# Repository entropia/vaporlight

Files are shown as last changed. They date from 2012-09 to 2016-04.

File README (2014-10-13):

Vaporlight
==========

The Vaporlight is Entropias LED lighting system.

More documentation (including pictures) is available
at https://entropia.de/Vaporlight.

Where to find what
------------------

/HACKING                       Describes some internals
/hardware                      Schematics and PCB layouts (Eagle)
/vaporware/led-boards          Firmware for the LED modules (C)
/config                        OpenOCD config files
/vaporware/emulator            Hardware emulator (Python)
/vaporware/daemon              TCP <-> Bus router (Scala)
/vaporware/language_bindings   Libraries for talking to the router (Python, C++)
/misc                          z.B. Schutzecken zum 3D-Drucken (OpenSCAD)

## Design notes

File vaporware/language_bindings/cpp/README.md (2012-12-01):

#Overview
This Reposetory provides a C++-Library that enables easy usage of the 
Vaporlight and a simple cli-tool to controll the LEDs directly.

## The library
The library provides an interface that is very easy to use and completly hides every networking or lowlevel-stuff from
it's users. It is implemented in a way that makes the usage of the header very cheap in compiletime though.

## The shell
The shell is a primitive userinterface for the vaporlight. Nevertheless it should be enough to do basic testing of the
vaporlight or figuring out, how the library can be used.

## License
vaporpp is free Software and licensed under the GNU Affero General Public License. (see license.txt)

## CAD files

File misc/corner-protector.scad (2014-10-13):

edge_length = 25;
edge_stop_length = edge_length - 10;
wall_width = 2;
wall_height = 2;
slot_height = 3;

total_height = 2 * wall_height + slot_height;

round_radius = 3;


// Rotate everything so that the long side points down
rotate([90,135,0])

// Construct body
difference() {
    // Outer extruded triangle
    linear_extrude(height = total_height, center = true, convexity = 10, $fn=100) {
        polygon(points=[[0,0],[edge_length,0],[0,edge_length]], paths=[[0,1,2]]);
    }

    // Inner extruded triangle
    linear_extrude(height = slot_height, center = true, convexity = 10, $fn=100) {
        polygon(points=[[wall_width,wall_width],[edge_length,wall_width],[wall_width,edge_length]], paths=[[0,1,2]]);
    }

    // Round off 90deg corner
    difference(){
        cube([2*round_radius,2*round_radius,total_height], center = true);

        translate([round_radius, round_radius, 0])
            cylinder (h = total_height, r=round_radius, center = true, $fn=100);
    }

    // Cut off 45deg corners
    translate([edge_length, 0, 0])
        rotate([0,0,45])
            cube([edge_length - edge_stop_length, edge_length - edge_stop_length, edge_length - edge_stop_length], center=true);
    translate([0, edge_length, 0])
        rotate([0,0,45])
            cube([edge_length - edge_stop_length, edge_length - edge_stop_length, edge_length - edge_stop_length], center=true);
}

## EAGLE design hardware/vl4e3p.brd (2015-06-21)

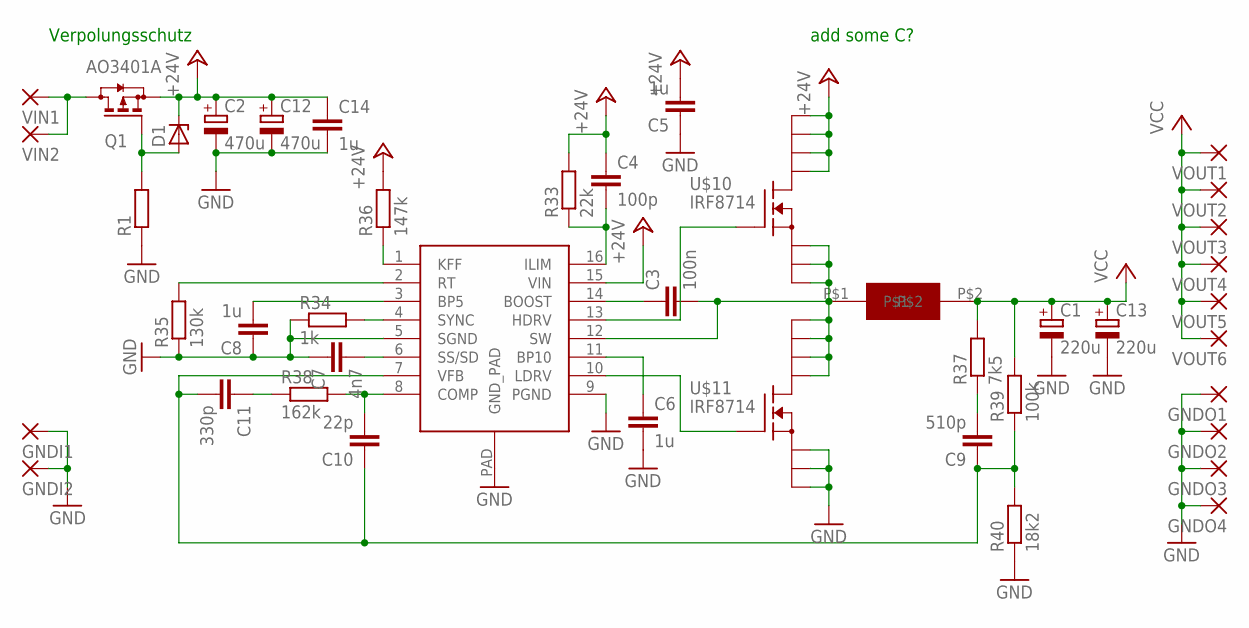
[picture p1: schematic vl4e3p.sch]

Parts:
C1, C13: 220u; E3,5-8
C2, C12: 470u; E3,5-8
C3: 100n; C0805S
C4: 100p; C0805
C5, C6, C8, C14: 1u; C0805
C7: 4n7; C0805
C9: 510p; C0805
C10: 22p; C0805
C11: 330p; C0805
D1: ZENER-DIODESOT23; SOT23
GNDI1, GNDI2: PAD5-2,5; 5-2,5
GNDO1, GNDO2, GNDO3, GNDO4: PAD5-2,5; 5-2,5
Q1: AO3401A; SOT23
R1: R-EU_R0805; R0805
R33: 22k; R0805
R34: 1k; R0805
R35: 130k; R0805
R36: 147k; R0805
R37: 7k5; R0805
R38: 162k; R0805
R39: 100k; R0805
R40: 18k2; R0805
U$1: 6u8; FOO
U$9: TPS40055; TSSOP16
U$10, U$11: IRF8714; SO8
VIN1, VIN2: PAD5-2,5; 5-2,5
VOUT1, VOUT2, VOUT3, VOUT4, VOUT5, VOUT6: PAD5-2,5; 5-2,5

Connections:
+24V: C2.+, C4.1, C5.2, C12.+, C14.1, D1.3 (C), Q1.2 (S), R33.2, R36.2, U$9.15 (VIN), U$10.5 (D), U$10.6 (D), U$10.7 (D), U$10.8 (D)
BOOST: C3.1, U$9.14 (BOOST)
BP10: C6.1, U$9.11 (BP10)
C3: C8.2, U$9.3 (BP5)
COMP: C10.2, R38.2, U$9.8 (COMP)
GND: C1.-, C2.-, C5.1, C6.2, C7.1, C8.1, C12.-, C13.-, C14.2, GNDI1.1, GNDI2.1, GNDO1.1, GNDO2.1, GNDO3.1, GNDO4.1, R1.1, R34.1, R35.1, R40.1, U$9.5 (SGND), U$9.9 (PGND), U$9.PAD (GND_PAD), U$11.1 (S), U$11.2 (S), U$11.3 (S)
HDRV: U$9.13 (HDRV), U$10.4 (G)
ILIM: C4.2, R33.1, U$9.16 (ILIM)
KFF: R36.1, U$9.1 (KFF)
LDRV: U$9.10 (LDRV), U$11.4 (G)
unnamed: C11.1, R38.1
unnamed: C9.2, R37.1
unnamed: D1.1 (A), Q1.1 (G), R1.2
RT: R35.2, U$9.2 (RT)
SS/SD: C7.2, U$9.6 (SS/SD)
SW: C3.2, U$1.P$1, U$9.12 (SW), U$10.1 (S), U$10.2 (S), U$10.3 (S), U$11.5 (D), U$11.6 (D), U$11.7 (D), U$11.8 (D)
SYNC: R34.2, U$9.4 (SYNC)
VCC: C1.+, C13.+, R37.2, R39.2, U$1.P$2, VOUT1.1, VOUT2.1, VOUT3.1, VOUT4.1, VOUT5.1, VOUT6.1
VFB: C9.1, C10.1, C11.2, R39.1, R40.2, U$9.7 (VFB)
VIN: Q1.3 (D), VIN1.1, VIN2.1

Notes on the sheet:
Verpolungsschutz
add some C?

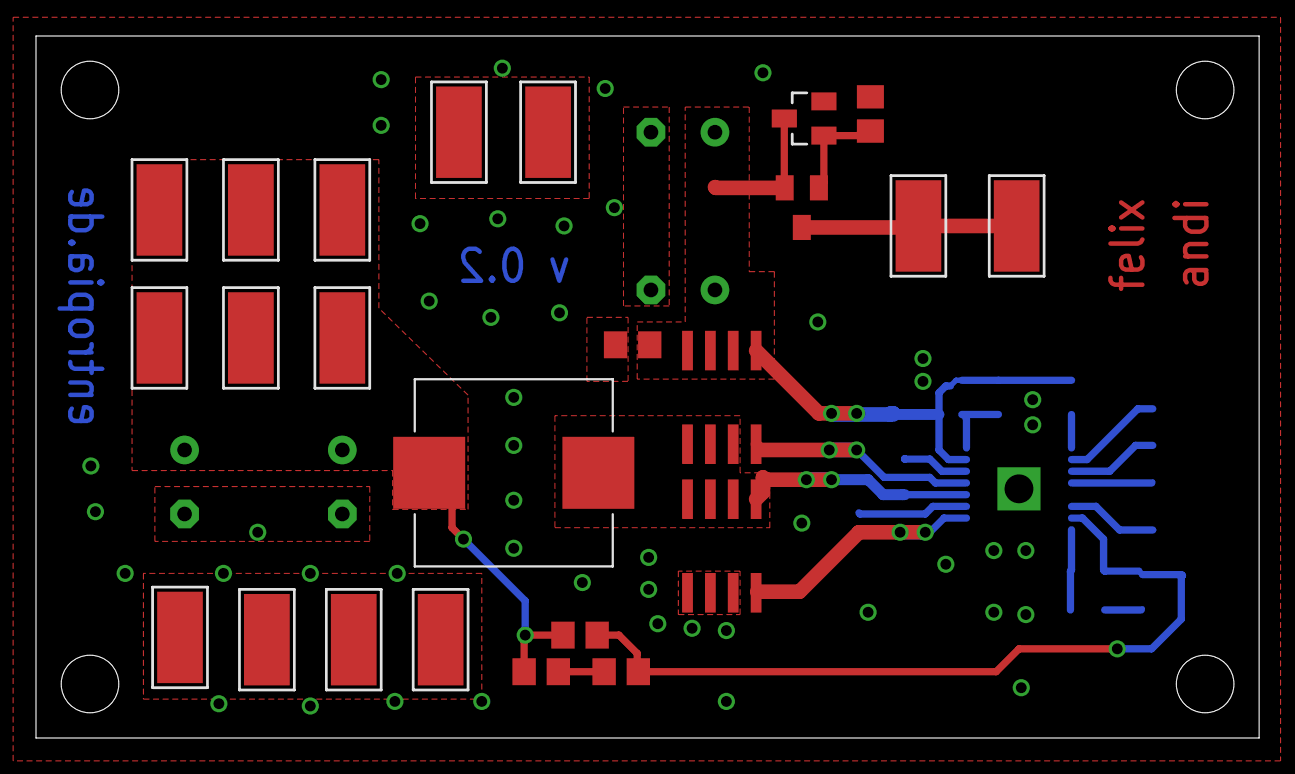
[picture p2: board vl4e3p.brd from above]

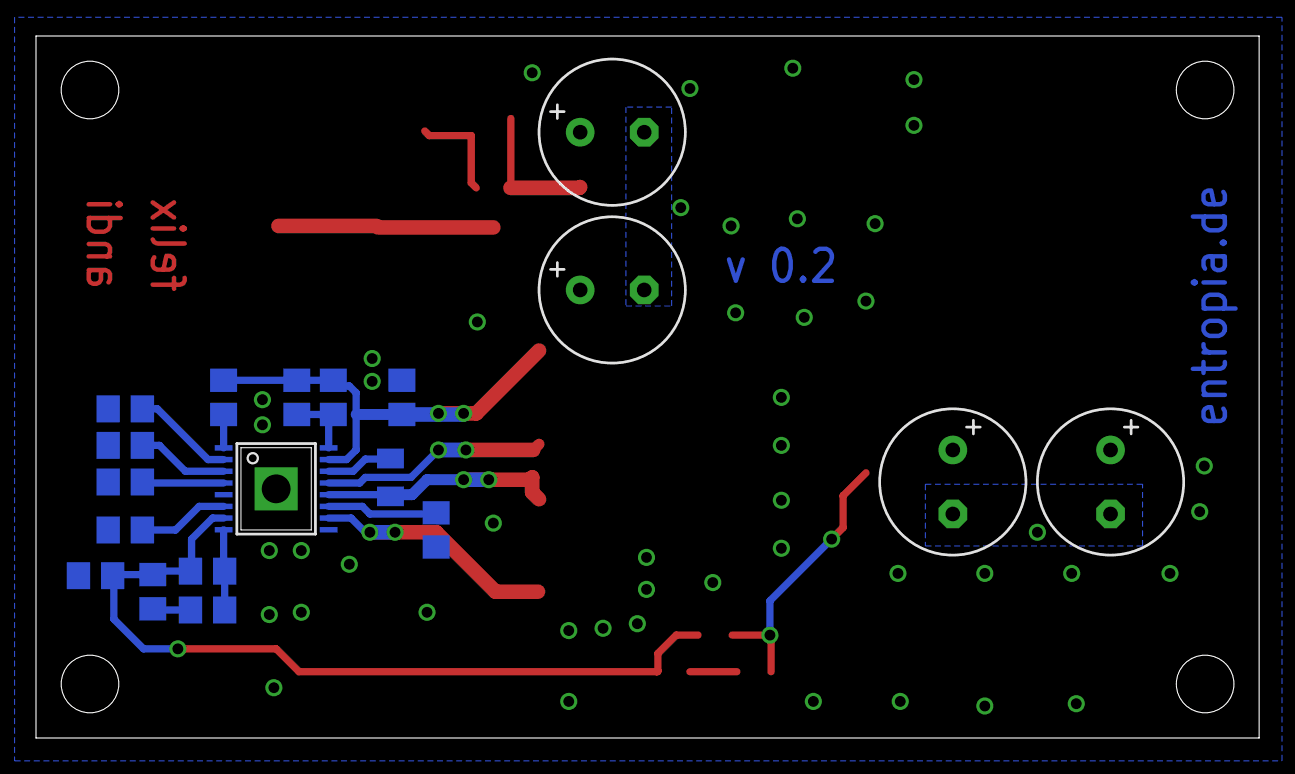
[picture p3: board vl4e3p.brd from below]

Board: 2 copper layers, 68.0 x 39.0 mm, 43 parts (19 on the bottom side), 20 nets.

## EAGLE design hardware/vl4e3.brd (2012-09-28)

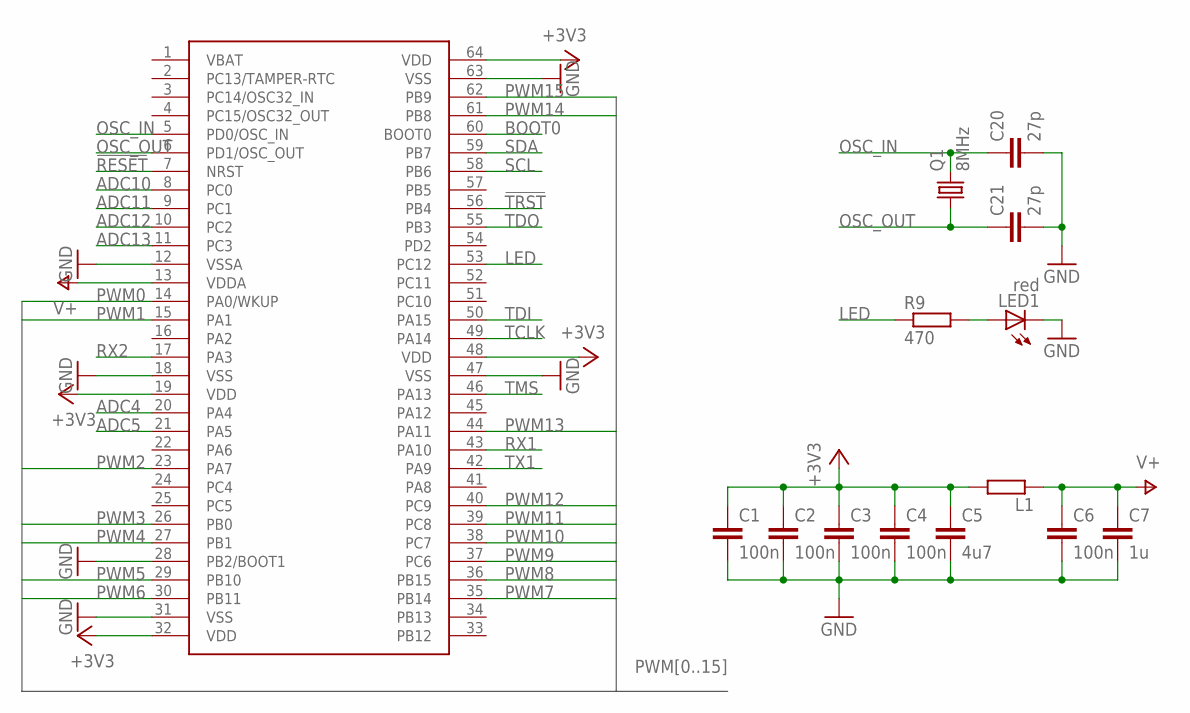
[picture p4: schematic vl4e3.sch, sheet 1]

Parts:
C1, C2, C3, C4, C6: 100n; C0603
C5: 4u7; C0805
C7: 1u; C0805
C20, C21: 27p; C0603
L1: R-EU_R0805; R0805
LED1: red; CHIPLED_0805
Q1: 8MHz; HC49/S
R9: 470; R0805
U$1: STM32F100R; TQFP64-10X10

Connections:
!RESET: U$1.7 (NRST); also elsewhere on the board
!TRST: U$1.56 (PB4); also elsewhere on the board
+3V3: C1.1, C2.1, C3.1, C4.1, C5.1, L1.2, U$1.19 (VDD), U$1.32 (VDD), U$1.48 (VDD), U$1.64 (VDD); also elsewhere on the board
ADC4: U$1.20 (PA4); also elsewhere on the board
ADC5: U$1.21 (PA5); also elsewhere on the board
ADC10: U$1.8 (PC0); also elsewhere on the board
ADC11: U$1.9 (PC1); also elsewhere on the board
ADC12: U$1.10 (PC2); also elsewhere on the board
ADC13: U$1.11 (PC3); also elsewhere on the board
BOOT0: U$1.60 (BOOT0); also elsewhere on the board
GND: C1.2, C2.2, C3.2, C4.2, C5.2, C6.2, C7.2, C20.2, C21.2, LED1.C, U$1.12 (VSSA), U$1.18 (VSS), U$1.28 (PB2/BOOT1), U$1.31 (VSS), U$1.47 (VSS), U$1.63 (VSS); also elsewhere on the board
LED: R9.1, U$1.53 (PC12)
LED_R: LED1.A, R9.2
OSC_IN: C20.1, Q1.2, U$1.5 (PD0/OSC_IN)
OSC_OUT: C21.1, Q1.1, U$1.6 (PD1/OSC_OUT)
PWM0: U$1.14 (PA0/WKUP); also elsewhere on the board
PWM1: U$1.15 (PA1); also elsewhere on the board
PWM2: U$1.23 (PA7); also elsewhere on the board
PWM3: U$1.26 (PB0); also elsewhere on the board
PWM4: U$1.27 (PB1); also elsewhere on the board
PWM5: U$1.29 (PB10); also elsewhere on the board
PWM6: U$1.30 (PB11); also elsewhere on the board
PWM7: U$1.35 (PB14); also elsewhere on the board
PWM8: U$1.36 (PB15); also elsewhere on the board
PWM9: U$1.37 (PC6); also elsewhere on the board
PWM10: U$1.38 (PC7); also elsewhere on the board
PWM11: U$1.39 (PC8); also elsewhere on the board
PWM12: U$1.40 (PC9); also elsewhere on the board
PWM13: U$1.44 (PA11); also elsewhere on the board
PWM14: U$1.61 (PB8); also elsewhere on the board
PWM15: U$1.62 (PB9); also elsewhere on the board
RX1: U$1.43 (PA10); also elsewhere on the board
RX2: U$1.17 (PA3); also elsewhere on the board
SCL: U$1.58 (PB6)
SDA: U$1.59 (PB7)
TCLK: U$1.49 (PA14); also elsewhere on the board
TDI: U$1.50 (PA15); also elsewhere on the board
TDO: U$1.55 (PB3); also elsewhere on the board
TMS: U$1.46 (PA13); also elsewhere on the board
TX1: U$1.42 (PA9); also elsewhere on the board
V+: C6.1, C7.1, L1.1, U$1.13 (VDDA)

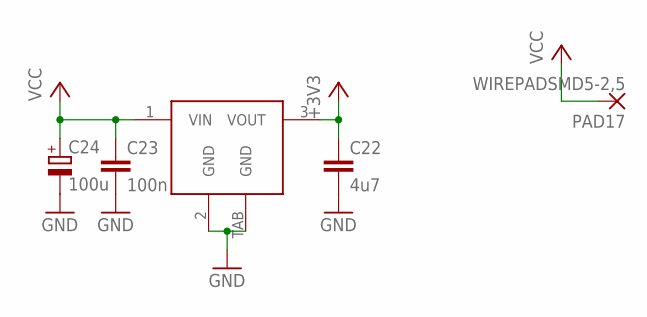
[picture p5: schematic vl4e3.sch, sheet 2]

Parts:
C22: 4u7; C0805
C23: 100n; C0603
C24: 100u; E2,5-6
PAD17: WIREPADSMD5-2,5; 5-2,5
U$10: MIC5209; SOT223

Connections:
+3V3: C22.1, U$10.3 (VOUT); also elsewhere on the board
GND: C22.2, C23.2, C24.-, U$10.2 (GND), U$10.TAB (GND); also elsewhere on the board
VCC: C23.1, C24.+, PAD17.1, U$10.1 (VIN); also elsewhere on the board

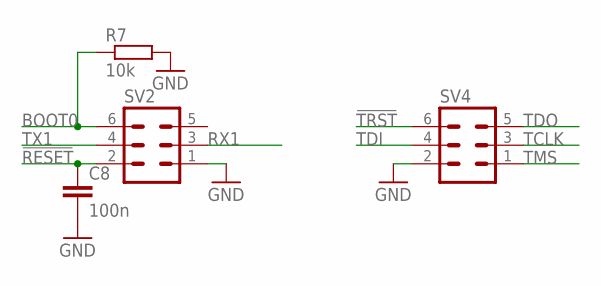
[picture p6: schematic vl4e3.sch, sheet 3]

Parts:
C8: 100n; C0603
R7: 10k; R0603
SV2, SV4: MA03-2

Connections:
!RESET: C8.1, SV2.2; also elsewhere on the board
!TRST: SV4.6; also elsewhere on the board
BOOT0: R7.1, SV2.6; also elsewhere on the board
GND: C8.2, R7.2, SV2.1, SV4.2; also elsewhere on the board
RX1: SV2.3; also elsewhere on the board
TCLK: SV4.3; also elsewhere on the board
TDI: SV4.4; also elsewhere on the board
TDO: SV4.5; also elsewhere on the board
TMS: SV4.1; also elsewhere on the board
TX1: SV2.4; also elsewhere on the board

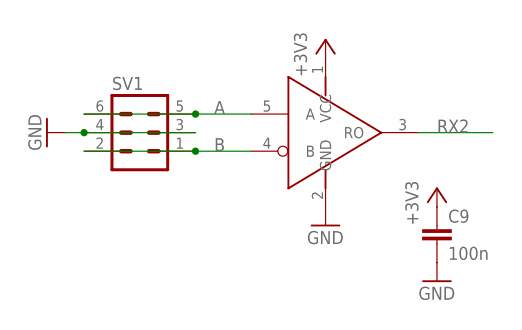
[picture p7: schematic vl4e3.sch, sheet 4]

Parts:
C9: 100n; C0603
SV1: MA03-2
U$13: ISL3280E; SOT23-5L

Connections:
+3V3: C9.1, U$13.1 (VCC); also elsewhere on the board
A: SV1.5, SV1.6, U$13.5 (A)
B: SV1.1, SV1.2, U$13.4 (B)
GND: C9.2, SV1.3, SV1.4, U$13.2 (GND); also elsewhere on the board
RX2: U$13.3 (RO); also elsewhere on the board

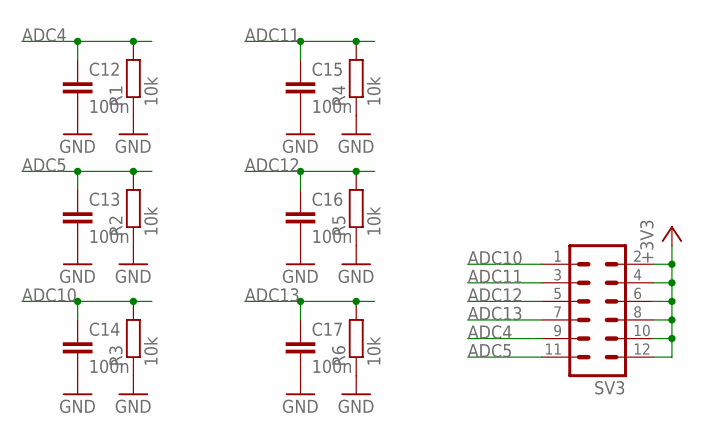
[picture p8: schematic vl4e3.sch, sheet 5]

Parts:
C12, C13, C14, C15, C16, C17: 100n; C0603
R1, R2, R3, R4, R5, R6: 10k; R0603
SV3: MA06-2

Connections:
+3V3: SV3.2, SV3.4, SV3.6, SV3.8, SV3.10, SV3.12; also elsewhere on the board
ADC4: C12.1, R1.2, SV3.9; also elsewhere on the board
ADC5: C13.1, R2.2, SV3.11; also elsewhere on the board
ADC10: C14.1, R3.2, SV3.1; also elsewhere on the board
ADC11: C15.1, R4.2, SV3.3; also elsewhere on the board
ADC12: C16.1, R5.2, SV3.5; also elsewhere on the board
ADC13: C17.1, R6.2, SV3.7; also elsewhere on the board
GND: C12.2, C13.2, C14.2, C15.2, C16.2, C17.2, R1.1, R2.1, R3.1, R4.1, R5.1, R6.1; also elsewhere on the board

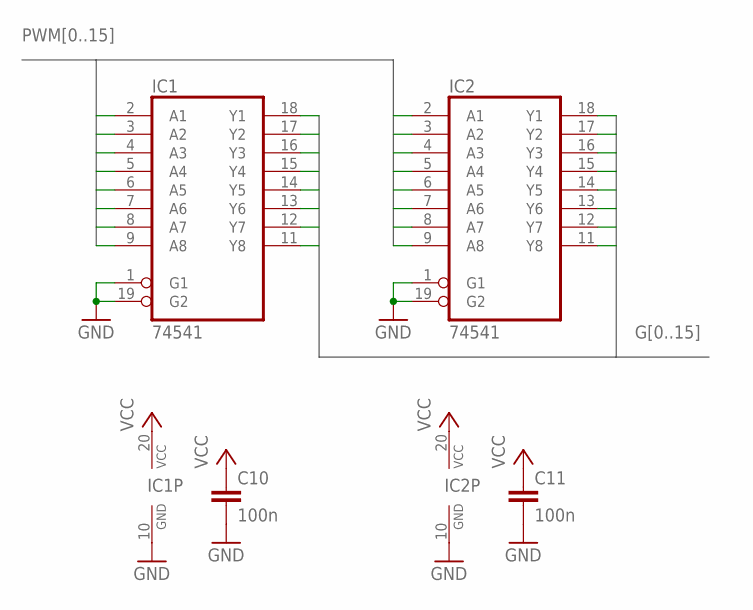
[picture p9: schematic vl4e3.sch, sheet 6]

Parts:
C10, C11: 100n; C0603
IC1, IC2: 74541; TSSOP20

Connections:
G0: IC1.18 (Y1); also elsewhere on the board
G1: IC1.17 (Y2); also elsewhere on the board
G2: IC1.16 (Y3); also elsewhere on the board
G3: IC1.15 (Y4); also elsewhere on the board
G4: IC1.14 (Y5); also elsewhere on the board
G5: IC1.13 (Y6); also elsewhere on the board
G6: IC1.12 (Y7); also elsewhere on the board
G7: IC1.11 (Y8); also elsewhere on the board
G8: IC2.18 (Y1); also elsewhere on the board
G9: IC2.17 (Y2); also elsewhere on the board
G10: IC2.16 (Y3); also elsewhere on the board
G11: IC2.15 (Y4); also elsewhere on the board
G12: IC2.14 (Y5); also elsewhere on the board
G13: IC2.13 (Y6); also elsewhere on the board
G14: IC2.12 (Y7); also elsewhere on the board
G15: IC2.11 (Y8); also elsewhere on the board
GND: C10.2, C11.2, IC1.1 (G1), IC1.10 (GND), IC1.19 (G2), IC2.1 (G1), IC2.10 (GND), IC2.19 (G2); also elsewhere on the board
PWM0: IC1.2 (A1); also elsewhere on the board
PWM1: IC1.3 (A2); also elsewhere on the board
PWM2: IC1.4 (A3); also elsewhere on the board
PWM3: IC1.5 (A4); also elsewhere on the board
PWM4: IC1.6 (A5); also elsewhere on the board
PWM5: IC1.7 (A6); also elsewhere on the board
PWM6: IC1.8 (A7); also elsewhere on the board
PWM7: IC1.9 (A8); also elsewhere on the board
PWM8: IC2.2 (A1); also elsewhere on the board
PWM9: IC2.3 (A2); also elsewhere on the board
PWM10: IC2.4 (A3); also elsewhere on the board
PWM11: IC2.5 (A4); also elsewhere on the board
PWM12: IC2.6 (A5); also elsewhere on the board
PWM13: IC2.7 (A6); also elsewhere on the board
PWM14: IC2.8 (A7); also elsewhere on the board
PWM15: IC2.9 (A8); also elsewhere on the board
VCC: C10.1, C11.1, IC1.20 (VCC), IC2.20 (VCC); also elsewhere on the board

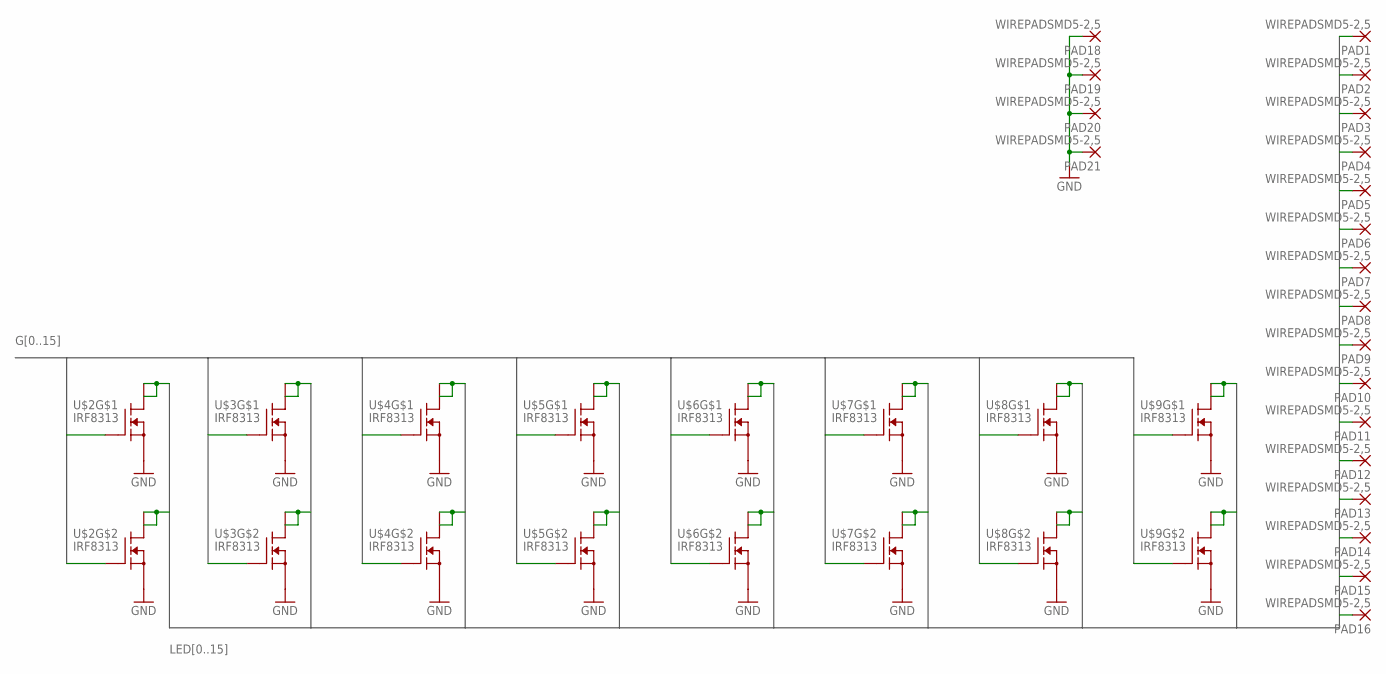
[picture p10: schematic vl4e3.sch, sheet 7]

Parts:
PAD1, PAD2, PAD3, PAD4, PAD5, PAD6, PAD7, PAD8, PAD9, PAD10, PAD11, PAD12, PAD13, PAD14, PAD15, PAD16, PAD18, PAD19, PAD20, PAD21: WIREPADSMD5-2,5; 5-2,5
U$2, U$3, U$4, U$5, U$6, U$7, U$8, U$9: IRF8313; SO-08

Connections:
G0: U$2.2 (G); also elsewhere on the board
G1: U$2.4 (G); also elsewhere on the board
G2: U$3.2 (G); also elsewhere on the board
G3: U$3.4 (G); also elsewhere on the board
G4: U$4.2 (G); also elsewhere on the board
G5: U$4.4 (G); also elsewhere on the board
G6: U$5.2 (G); also elsewhere on the board
G7: U$5.4 (G); also elsewhere on the board
G8: U$6.2 (G); also elsewhere on the board
G9: U$6.4 (G); also elsewhere on the board
G10: U$7.2 (G); also elsewhere on the board
G11: U$7.4 (G); also elsewhere on the board
G12: U$8.2 (G); also elsewhere on the board
G13: U$8.4 (G); also elsewhere on the board
G14: U$9.2 (G); also elsewhere on the board
G15: U$9.4 (G); also elsewhere on the board
GND: PAD18.1, PAD19.1, PAD20.1, PAD21.1, U$2.1 (S), U$2.3 (S), U$3.1 (S), U$3.3 (S), U$4.1 (S), U$4.3 (S), U$5.1 (S), U$5.3 (S), U$6.1 (S), U$6.3 (S), U$7.1 (S), U$7.3 (S), U$8.1 (S), U$8.3 (S), U$9.1 (S), U$9.3 (S); also elsewhere on the board
LED0: PAD1.1, U$2.7 (D), U$2.8 (D)
LED1: PAD2.1, U$2.5 (D), U$2.6 (D)
LED2: PAD3.1, U$3.7 (D), U$3.8 (D)
LED3: PAD4.1, U$3.5 (D), U$3.6 (D)
LED4: PAD5.1, U$4.7 (D), U$4.8 (D)
LED5: PAD6.1, U$4.5 (D), U$4.6 (D)
LED6: PAD7.1, U$5.7 (D), U$5.8 (D)
LED7: PAD8.1, U$5.5 (D), U$5.6 (D)
LED8: PAD9.1, U$6.7 (D), U$6.8 (D)
LED9: PAD10.1, U$6.5 (D), U$6.6 (D)
LED10: PAD11.1, U$7.7 (D), U$7.8 (D)
LED11: PAD12.1, U$7.5 (D), U$7.6 (D)
LED12: PAD13.1, U$8.7 (D), U$8.8 (D)
LED13: PAD14.1, U$8.5 (D), U$8.6 (D)
LED14: PAD15.1, U$9.7 (D), U$9.8 (D)
LED15: PAD16.1, U$9.5 (D), U$9.6 (D)

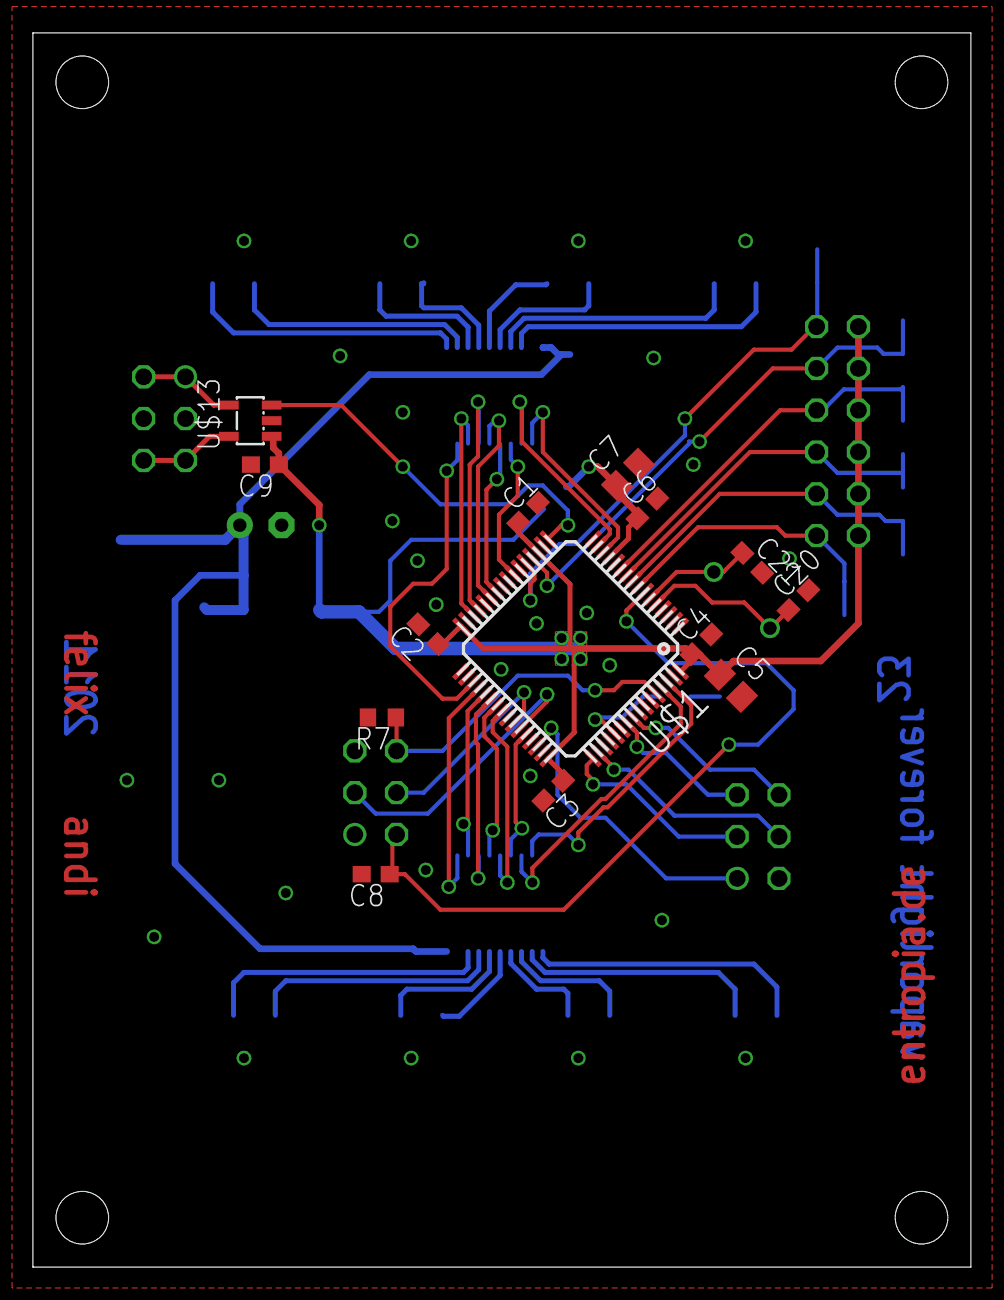
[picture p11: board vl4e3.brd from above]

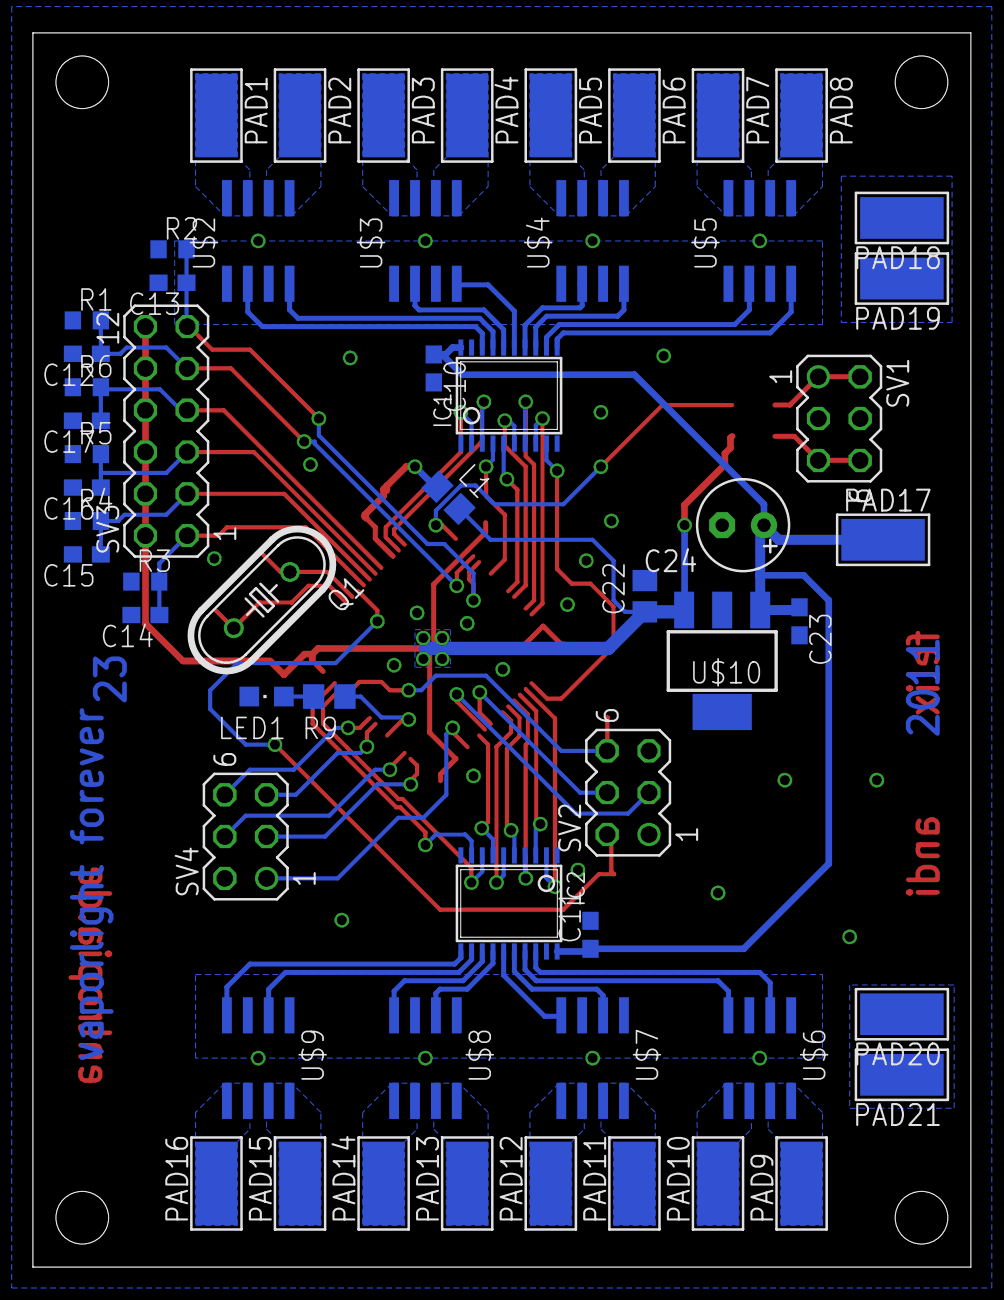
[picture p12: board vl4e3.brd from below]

Board: 2 copper layers, 57.0 x 75.0 mm, 71 parts (57 on the bottom side), 74 nets.

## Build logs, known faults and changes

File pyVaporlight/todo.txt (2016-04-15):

- Lua implementation not testet yet
- write lua effects
- rewrite config style
- Flask frontend
    - control lua scripts
    - control master brightness
    - see all running vaporlight effects (incl. vapornet)

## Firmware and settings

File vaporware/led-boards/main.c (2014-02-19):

/*
  This is the main program file for the Vaporlight Forever LED board controller.
*/
#include "main.h"

#include "color.h"
#include "command.h"
#include "config.h"
#include "console.h"
#include "debug.h"
#include "error.h"
#include "fail.h"
#include "git_version.h"
#include "heat.h"
#include "pwm.h"
#include "usart1.h"
#include "usart2.h"

/*
 * Set to 1 by the systick timer when a heat check
 * should be done.
 */
volatile int do_heat_check;

/*
 * What to do when overheat is detected.
 */
static void panic_on_overheat() {
	pwm_set_state(PWM_STOP);
	error(ER_HEAT, STR_WITH_LEN("Overheat!"), EA_RESET);
}

/*
 * Display the current git revision as colors.
 *
 * If there is no channel mapping yet, display a dim white instead.
 */
static void display_boot_colors(bool have_channel_mapping) {
	uint32_t mask = 1 << 31;

	for(uint8_t c = 0; c < 15; c++) {
		if(have_channel_mapping) {
			uint8_t pwm_channel = convert_channel_index(c);

			pwm_set_brightness(pwm_channel, (GIT_VERSION_HEX & mask) ? 0xFFFF : 0x0);

			mask >>= 1;
		} else {
			pwm_set_brightness(c, 0x7FFF);
		}
	}

	pwm_send_frame();
}

/*
 * Main program. Initializes all the modules and then enters the main loop.
 * The actual work is done in command.c.
 */
int main() {
	unsigned char *command;
	error_t ret;
	vl_mode_t mode;

	usart1_init();

#ifdef TRACE_STARTUP
	dled_off();
#endif

	pwm_init();

	heat_init(panic_on_overheat);

	ret = load_config();

	// Display the version number on lights during bootup
	display_boot_colors(ret == E_SUCCESS);

	mode = console_ask_mode();

	pwm_set_state(PWM_STOP);

	if (ret == E_SUCCESS) {
		// We are running in normal mode with config available.
		// That's OK.
	} else if (ret == E_NOCONFIG && mode != CONFIG_MODE) {
		error(ER_NO_CONFIG, STR_WITH_LEN("No configuration found"), EA_PANIC);
	} else if (ret != E_NOCONFIG && ret != E_SUCCESS) {
		error(ER_BUG, STR_WITH_LEN("Flash read error"), EA_PANIC);
	} else {
		// We are running in config mode with no config available.
		// That's OK.
	}

	// Enable interrupts for heat check.
	__asm("cpsie i");

	pwm_set_state(PWM_ON);

	// If we are running in config mode, first start the config
	// console.  The user may choose to continue running the board
	// after configuration is done, so we must be able to continue
	// as if in normal mode.
	if (mode == CONFIG_MODE) {
		console_run();
	}

	// We are now, regardless of the value of mode, in normal mode.

	command_init();
	usart2_init();

	while (1) {
		command = usart2_next_command();

		if (command != (unsigned char*) 0) {
#ifdef TRACE_COMMANDS
			debug_string("C:");
#endif
			ret = run_command(command);

			if (ret != E_SUCCESS) {
				error(ER_USART_RX, STR_WITH_LEN("Bogus USART command."), EA_RESUME);
#ifdef TRACE_ERRORS
				debug_sint(ret, 0);
				debug_string(" ");
				for (int i = 0; i < 36; i++) {
					debug_hex(command[i], 2);
				}
#endif
			}
		}

		if (do_heat_check) {
#ifdef TRACE_HEAT
			debug_string("H\n");
#endif
			heat_timer_tick();

			do_heat_check = 0;
		}
	}

	error(ER_BUG, STR_WITH_LEN("End of main reached!"), EA_PANIC);

	return 0;
}

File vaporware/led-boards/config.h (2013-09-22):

#ifndef CONFIG_H
#define CONFIG_H

#include <stdint.h>
#include "stm_include/stm32/timer.h"

#include "error.h"
#include "fixedpoint.h"
#include "pwm.h"

/*
 * Configuration to be set at compile time.
 */

// Number of milliseconds to wait between switching of the debug LED.
#define DEBUG_LED_SPEED 125 // 1/8 seconds per dot.

// Length of this module in LEDs
#define MODULE_LENGTH 16

#define RGB_LED_COUNT ((MODULE_LENGTH)/3)

// Mapping from timer channels to PWM registers.
static volatile uint32_t * const TIMER_CHANNELS[MODULE_LENGTH] = {
	&TR(TIM2,  CCR1),
	&TR(TIM2,  CCR2),
	&TR(TIM1,  CCR1),
	&TR(TIM1,  CCR2),
	&TR(TIM1,  CCR3),
	&TR(TIM2,  CCR3),
	&TR(TIM2,  CCR4),
	&TR(TIM15, CCR1),
	&TR(TIM15, CCR2),
	&TR(TIM3,  CCR1),
	&TR(TIM3,  CCR2),
	&TR(TIM3,  CCR3),
	&TR(TIM3,  CCR4),
	&TR(TIM1,  CCR4),
	&TR(TIM16, CCR1),
	&TR(TIM17, CCR1)
};

// Baud rate register for the USARTs.
#if BUS_BAUDRATE == 115200
// Divider 13.0 * 16 = 208.3: 115200 baud at 24MHz
static const int USART_BAUD_VALUE = (13 << 4) | 0;
#else
 #if BUS_BAUDRATE == 500000
// Divider 3.0 * 16 = 48.0: 500000 baud at 24MHz
static const int USART_BAUD_VALUE = (3 << 4) | 0;
 #else
  #error "Only baud rates 115200 and 500000 are supported"
 #endif
#endif
// Divider 13.0 * 16 = 208.3: 115200 baud at 24MHz
static const int CONSOLE_BAUD_VALUE = (13 << 4) | 0;

// Timeout for the user reaction to enter config mode, in ms.
static const int ASK_MODE_TIMEOUT = 3000;

// Number of failures on which to raise an error.
static const int USART_FAIL_TRESHOLD = 20;

// Number of USART command buffers.
#define USART_BUFFER_COUNT 4
// Length of a USART command buffer
#define CMD_BUFFER_LEN 36

// Start-of-command marker
#define START_MARK 0x55
// Byte used for escaping
#define ESCAPE_MARK 0x54

// Temperature sensor count
#define HEAT_SENSOR_LEN 6


// Number base used for reading user input in the config console.
#define CONSOLE_READ_BASE 10


// Temperature sensor ADC ports
static const uint8_t HEAT_ADC_PORTS[HEAT_SENSOR_LEN] = {
	4,
	5,
	10,
	11,
	12,
	13,
};

// How many bits to use for the PWM.
#define PWM_BITS 16

// The value to which the PWM counters will be reset.
#if PWM_BITS == 16
	// Use 0xfffe so that a value of 0xffff is really 100% on
	#define PWM_RELOAD 0xfffe
#else
	#define PWM_RELOAD ((1 << PWM_BITS) - 1)
#endif

// Sample time for the heat sensors.
#define ADC_SAMPLE_TIME 0x7 // 239.5 cycles (50kHz)
static const int ADC_SAMPLE_TIME_1 =
	((ADC_SAMPLE_TIME & 0x7) << 0) |
	((ADC_SAMPLE_TIME & 0x7) << 3) |
	((ADC_SAMPLE_TIME & 0x7) << 6) |
	((ADC_SAMPLE_TIME & 0x7) << 9) |
	((ADC_SAMPLE_TIME & 0x7) << 12) |
	((ADC_SAMPLE_TIME & 0x7) << 15) |
	((ADC_SAMPLE_TIME & 0x7) << 18) |
	((ADC_SAMPLE_TIME & 0x7) << 21);

static const int ADC_SAMPLE_TIME_2 =
	((ADC_SAMPLE_TIME & 0x7) << 0) |
	((ADC_SAMPLE_TIME & 0x7) << 3) |
	((ADC_SAMPLE_TIME & 0x7) << 6) |
	((ADC_SAMPLE_TIME & 0x7) << 9) |
	((ADC_SAMPLE_TIME & 0x7) << 12) |
	((ADC_SAMPLE_TIME & 0x7) << 15) |
	((ADC_SAMPLE_TIME & 0x7) << 18) |
	((ADC_SAMPLE_TIME & 0x7) << 21) |
	((ADC_SAMPLE_TIME & 0x7) << 24) |
	((ADC_SAMPLE_TIME & 0x7) << 27);

// Number of failures on which to raise an error.
static const int HEAT_FAIL_TRESHOLD = 20;

// Initial contents of Flash.
// This should be the value that the Flash contains when not programmed.
static const uint8_t EEPROM_EMPTY = 0xFF;

// Size of the config page in flash pages. When changing, the linker script
// must be edited accordingly.
#define CONFIG_PAGES 1

// Values of configuration entry status.
static const uint16_t CONFIG_ENTRY_EMPTY = 0xffff; // Should be default Flash value.
static const uint16_t CONFIG_ENTRY_IN_USE = 0x5555;
static const uint16_t CONFIG_ENTRY_OLD = 0x0000;

/*
 * Configuration to be read from Flash.
 */

/*
 * Canonical indices for the colors.
 */
typedef enum {
	RED   = 0,
	GREEN = 1,
	BLUE  = 2
} color_t;

/*
 * Information for color correction of a single LED, and conversion
 * from LED colors to PWM channels.
 */
typedef struct {
	// The fillers are required for static initialization
	// with 0xff bytes (needed for flash pages).

	// 3*3 matrix for color correction.
	// This converts an input
	//      ( x )
	// xy = ( y )
	//      ( 1 )
	// to the ratio of red, green and blue PWM channels necessary
	// to repreduce the color (if possible).
	// ( r )
	// ( g ) = color_matrix * xy;
	// ( b )
	union {
		fixed_t color_matrix[9];
		char filler1[9 * sizeof(fixed_t)];
	};

	// The luminosity of each channel at maximum PWM setting.
	union {
		fixed_t peak_Y[3];
		char filler2[3 * sizeof(fixed_t)];
	};

	// Index of the PWM channels for red, green and blue.
	uint8_t channels[3];
} __attribute__ ((packed)) led_info_t;
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

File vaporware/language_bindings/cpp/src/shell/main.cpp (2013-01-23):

/*
 *  This file is part of vaporpp.
 *
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
 *  You should have received a copy of the GNU General Public License
 *  along with vaporpp.  If not, see <http://www.gnu.org/licenses/>.
 */


#include <cstdint>
#include <iostream>
#include <stdexcept>
#include <map>

#include <boost/algorithm/string.hpp>
#include <boost/program_options.hpp>

#include "../lib/client.hpp"

#include "console.hpp"
#include "commands.hpp"

int main(int argc, char**argv) {
	using std::string;
	namespace bpo = boost::program_options;
	
	string server;
	string token;
	uint16_t port;
	
	bpo::options_description desc;
	desc.add_options()
	("help,h", "print this help")
	("verbose,v", "be verbose")
	("token,t", bpo::value<std::string>(&token), "sets the authentication-token")
	("server,s", bpo::value<std::string>(&server), "sets the servername")
	("port, p", bpo::value<uint16_t>(&port)->default_value(vlpp::client::DEFAULT_PORT), "sets the server-port");
	
	bpo::variables_map vm;
	bpo::store(bpo::parse_command_line(argc, argv, desc) ,vm);
	bpo::notify(vm);
	if (vm.count("help")) {
		std::cout << desc << std::endl;
		return 0;
	}
	
	if (vm.count("verbose")) {
		std::cout << "server = “" << server << "”\n"
		          << "token = “" << token << "”\n"
		          << "port = " << port << std::endl;
	}
	
	vlpp::client client(server, token, port);
	
	string line;
	std::map<string, string> argmap {
		{"s", "set"},
		{"a", "add"},
		{"q", "quit"},
		{"h", "help"},
		{"f", "flush"},
		{"auth", "authenticate"}
	};
	while (readln(line, "-> ")) {
		boost::algorithm::trim(line);
		if (line.empty()) {
			continue;
		}
		auto cmd = parse_cmd(line, argmap);
		
		if (cmd.first == "set" || cmd.first == "add") {
			if (cmd.second.size() != 2) {
				std::cerr << "Error: “"<< cmd.first 
					  << "” takes exactly two arguments" << std::endl;
				continue;
			}
			try {
				set_leds(client, cmd.second[0], cmd.second[1]);
				if(cmd.first == "set") {
					client.flush();
				}
			}
			catch
				(std::invalid_argument& e) {
				std::cerr << "Error: " << e.what() << std::endl;
				continue;
			}
			catch
				(std::runtime_error& e) {
				std::cerr << "Error: " << e.what() << std::endl;
				return 1;
			}
		}
		else if(cmd.first == "flush"){
			client.flush();
		}
		else if(cmd.first == "help"){
			print_cli_help();
		}
		else if (cmd.first == "quit") {
			break;
		}
		// note: not yet documented for the problem that 
		// whitespace will get stripped out to early:
		else if (cmd.first == "authenticate") {
			if (cmd.second.size() != 1) {
				std::cerr << "Error: you have to provide a token" << std::endl;
				continue;
			}
			try{
				client.authenticate(cmd.second[0]);
			}
			catch(std::invalid_argument& e){
				std::cerr << "Error: " << e.what() << std::endl;
			}
		}
		else {
			std::cerr << "Error: unknown command: “" << cmd.first << "”" << std::endl;
		}
	}
	
	return 0;
}

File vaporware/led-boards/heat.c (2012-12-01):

#include "heat.h"

#include "config.h"
#include "error.h"
#include "fail.h"

#include "stm_include/stm32/adc.h"
#include "stm_include/stm32/dma.h"
#include "stm_include/stm32/nvic.h"
#include "stm_include/stm32/systick.h"

/*
 * The function to be called when overheat occurs.
 */
static heat_handler_t overheat_handler;

/*
 * The samples got from the ADC will be writter here by DMA.
 */
static int adc_samples[HEAT_SENSOR_LEN];

/*
 * The failure logs for each heat sensor
 */
static fail_t heat_fails[HEAT_SENSOR_LEN];

/*
 * Returns the sequence register where the n'th conversion
 * is to be stored. If n = 17, the sequence length field is returned.
 */
static volatile uint32_t *seq_register_for(unsigned int n) {
	if (n > 17) {
		error(ER_BUG, STR_WITH_LEN("ADC sequence too long"), EA_PANIC);
	}

	if (n <= 6) {
		return &ADC1_SQR3;
	} else if (n <= 12) {
		return &ADC1_SQR2;
	} else {
		return &ADC1_SQR1;
	}
}

/*
 * Returns the bit position in the sequence register where
 * the n'th conversion is to be stored. If n = 17 the position
 * of the sequence length field is returned.
 */
static int bit_position_for(unsigned int n) {
	if (n > 17) {
		error(ER_BUG, STR_WITH_LEN("ADC sequence too long"), EA_PANIC);
	}

	// Each register contains the following conversions (for one k)
	// 6k + 1 at bits  4 to  0
	// ...
	// 6k + 6 at bits 29 to 25
	// This formula follows:
	return ((n-1) % 6) * 5;
}

/*
 * Initializes temperature sensors. When this function has been called,
 * a heat check will be done at each system timer tick.
 */
void heat_init(heat_handler_t on_overheat) {
	overheat_handler = on_overheat;

	for (int s = 0; s < HEAT_SENSOR_LEN; s++) {
		fail_init(&heat_fails[s], HEAT_FAIL_TRESHOLD);
	}

	// Configure the ADC in the following way:
	// Put the values from HEAT_ADC_PORTS into the sequence registers
	// Start ADC in scan mode with continuous bit set.
	// Configure DMA to write samples to adc_samples.

	// Write ADC ports into sequence registers.
	_Static_assert(HEAT_SENSOR_LEN <= 16, "Too many heat sensors!");
	for (int i = 0; i < HEAT_SENSOR_LEN; i++) {
		*seq_register_for(i) = (HEAT_ADC_PORTS[i] & 0xf) << bit_position_for(i);
	}
	// Write length into sequence length field.
	*seq_register_for(17) = HEAT_SENSOR_LEN << bit_position_for(17);

	// Set up ADC
	ADC1_CR1 = ADC_CR1_SCAN | // Scan mode
		ADC_CR1_EOCIE;    // End of conversion interrupt enable
	ADC1_CR2 = ADC_CR2_CONT | // Continuous mode.
		ADC_CR2_DMA;      // DMA mode
	ADC1_SMPR1 = ADC_SAMPLE_TIME_1;
	ADC1_SMPR2 = ADC_SAMPLE_TIME_2;
	

	// Set up DMA (using channel 1 of DMA 1 here)
	DMA1_CPAR1 = (uint32_t) &ADC1_DR;
	DMA1_CMAR1 = (uint32_t) &adc_samples;
	DMA1_CNDTR1 = HEAT_SENSOR_LEN;
	DMA1_CCR1 = (DMA_CCR1_PL_HIGH << DMA_CCR1_PL_LSB) |    // High priority
		(DMA_CCR1_MSIZE_16BIT << DMA_CCR1_MSIZE_LSB) | // 16 bit memory size
		(DMA_CCR1_PSIZE_16BIT << DMA_CCR1_PSIZE_LSB) | // 16 bit peripheral size
		DMA_CCR1_MINC |                                // Memory auto-increment
		DMA_CCR1_CIRC |                                // Circular mode
		DMA_CCR1_EN;                                   // enable

	// Enable ADC interrupt in NVIC
	NVIC_ISER(0) |= (1 << NVIC_ADC1_2_IRQ);

	ADC1_CR2 |= ADC_CR2_ADON;

	// Enable Systick timer, enable interrupt.
	// (heat_timer_tick will be called at each systick)
	STK_CTRL = STK_CTRL_TICKINT | STK_CTRL_ENABLE;
}

/*
 * This function does a heat check on every system timer tick.
 */
void heat_timer_tick() {
	for (int s = 0; s < HEAT_SENSOR_LEN; s++) {
		if (fail_event(&heat_fails[s], (adc_samples[s] > config.heat_limit[s]))) {
			overheat_handler();
			return;
		}
	}
}

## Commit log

2012-09-28 Added first hardware designs (by @felixheld).
    This contains the controller board for the LED modules and the step-down
    converter for the LEDs.
    [vl4e3.brd, vl4e3.sch, vl4e3p.brd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]
2012-09-28 Upgrade vl4e3 to EAGLE 6.0 file format
    Upgrade the file format of the control board
    to the plain-text EAGLE 6.0 format.
    [vl4e3.brd, vl4e3.sch]
2012-10-17 add configuration for OpenOCD
    This adds a customized version of the OpenOCD stm32f1x target with a
    lower WORKAREASIZE to account for the lower amount of available memory
    on the Vaporlight boards.
    [vaporlight.cfg]
2012-12-01 Second public release of the firmware.
    Major changes:
    - Gamma table can be read and updated at runtime.
    - Low-level improvements to the console: It is now interrupt-driven and
    uses flow control. This makes it possible to paste configuration files
    into the console without losing data.
2012-12-07 added torture-device and made pimpl less painfull
2012-12-08 replaced manual locking by lock-guard
    [main.cpp]
2013-03-30 Emulator: Bugfix: sample file was missing strobe command
2013-03-30 Emulator can now use stdin instead of sockets
2013-03-31 Emulator: set-led with invalid indices just does nothing
2013-03-31 Emulator: debug output: print received frames
2013-04-16 New overlays are transparent (not black) by default now
    This way, the output doesn't change if a client just
    connects and authenticates but does not actually set
    any LEDs.
2013-04-16 Bugfix: double strobe
    This is a workaround for a problem with the bus protocol:
    Because of how framing works, the Vaporlight firmware currently
    only detects the end of a frame by waiting for the beginning of
    the next frame. This is problematic if only a single strobe
    without further messages is sent.
2013-04-17 Bugfix: for when only some LEDs of a module are updated
2013-04-17 Add lost connection handling
    When a client disconnects, its overlay is removed from the mixer
    and the LEDs are updated accordingly.
    Individual tokens can be marked as persistent. The overlays
    for these tokens are kept even when the connection is closed.
2013-04-20 Ignore invalid set-led
    Don't throw when theres no mapping for a LED
2013-04-26 Oops, the actual LED modules have 16 leds
2013-04-26 Add "file" device type
    Somewhat useful for debugging; this way one can use a hex editor
    to check what the router would send to the hardware
2013-07-23 Fix openocd config
    [vaporlight.cfg]
2013-07-23 Add openocd config file for our JTAG adapter
    [olimex-arm-usb-tiny-h.cfg]
2013-09-18 Fix console system reset command.
    [console_prompt.c]
2013-09-22 Move module "led" to "pwm".
2013-09-22 Remove LED color setting (to be replaced by proper calibration).
    [config.h, console_prompt.c]
2013-09-22 Change pwm_set_brightness to take 16-bit values.
2013-09-22 Remove whitepoint correction setting (to be replaced by calibration).
    [config.h, console_prompt.c]
2013-09-22 Implemented color calibration. Compiler change was necessary.
2013-09-22 Remove LED permutation config, fix flash config page.
    [command.c, config.h, console_prompt.c]
2013-09-22 Refactoring: Introduce RGB_LED_COUNT, clear distinction LED <-> PWM channel.
2013-09-22 Implemented console functions to set up correction and maximum Y value.
    [console_prompt.c]
2013-09-22 Implemented new 16-bit "set LEDs" command.
2013-09-22 Add config check for valid PWM channel assignment.
2013-09-22 Remove whitepoint calibration mode.
2013-09-22 Add LED calibration command.
2013-09-22 Implement fixed-point arithmetic and replace all float operations.
    [config.h, console_prompt.c]
2013-09-22 Fix linker script (take care of the .ARM.exidx section).
2013-09-22 Remove all pointers to led_info_t.
    Pointing to a packed struct is undefined.
2013-09-22 Add cycle counting for the "set LEDs" command.
2013-09-24 Daemon: use new bus protocol
    This is just a quick fix; we don't make use of the
    new features yet:
    - we set raw pwm values instead of xyY colors
    - we use only 8 bit precision instead of 16
2013-09-27 Daemon: add HighPrecisionSetMessage
    This makes it possible to specify colors using 16-bit precision.
    Opcode 0x03, payload bytes: mlRrGgBbAa (m: module, l: led).
2013-09-27 Document the new 16-bit set-led command
2013-09-29 Daemon: add web server
    It offers a simple API that can currently be used
    to control a global dimmer and a backlight.
    It will always listen on 0.0.0.0:8080
2013-11-10 Implement the new RS485 bus protocol in the LED board firmware.
    See also HACKING.
2014-02-17 Fix a desynchronisation bug.
    When a start byte was received during a frame, the message that was being
    assembled at the time was not correctly cleaned up.
2014-02-17 firmware: actually update pwm state in display_version()
2014-02-19 Firmware: Do not blink a debug code for transient failures.
    [error.c]
2014-05-11 Firmware: Add implicit LED update for pwm_set_state(PWM_ZERO).
2014-05-11 Firmware: Update OpenOCD interface script to work with openocd 0.8.0.
    [olimex-arm-usb-tiny-h.cfg]
2014-07-20 Fix rainbow demo script
    [rainbow.py]
2014-10-13 Corner protection guards
    The vaporlight case corners are quite sharp.
    [corner-protector.scad]
2015-06-21 hardware: update stepdown schematic to eagle 6.5
    [vl4e3p.sch]
2015-06-21 hardware: increase current limit of stepdown
    The old resistor value was based on a very tightly calculated current
    limit and was also rounded down to match an E12 value. This caused some
    aging Vaporlights to fail when drawing more current (e.g. displaying all
    white).
    [vl4e3p.brd, vl4e3p.sch]
2016-10-21 Language bindings (+example) for rust.
    The vaporlight package can also be found on crates.io
    [main.rs]

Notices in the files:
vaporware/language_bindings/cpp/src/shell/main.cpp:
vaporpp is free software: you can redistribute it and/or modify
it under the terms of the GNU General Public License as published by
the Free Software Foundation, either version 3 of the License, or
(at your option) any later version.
